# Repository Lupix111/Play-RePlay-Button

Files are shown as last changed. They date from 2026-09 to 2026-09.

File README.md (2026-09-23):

# Play/Replay







**Play/Replay** turns a Raspberry Pi Pico into a hardware-backed macro recorder for keyboard and mouse input. Press a button, do things on your PC, press it again and the exact sequence of keystrokes and mouse movement, down to the MILLISECOND, is stored on the Pico's own flash. Press the second button and it plays back on any USB host, looping forever until you stop it. No host PC or driver required.

## Why this exists

Most macro recorder tools live entirely in software on one machine: they hook the OS, store the macro in a config file, and replay it through the same OS's input APIs. That's bull-dookie (breaks across reboots, requires the software running, tied to one OS) and it can't target a *different* machine than the one you recorded on.

Play/Replay splits the job in two:

- **The Capture** happens at the OS level on a source PC because that's the only place you can reliably see input from *any* keyboard, including a laptop's built-in one, which never appears on an external USB bus.
- **Storage and playback** happen entirely on the Pico, as a real USB HID device. Once a macro is recorded the Pico can be unplugged from the source PC and plugged into any other USB host, it will type and click exactly like a human, **indistinguishable** at the protocol level from a real keyboard/mouse.

## Features

- Millisecond-accurate timing between every event (key press/release, mouse move, click, scroll)
- Two-button workflow: button 1 toggles recording, button 2 toggles looping playback (repeats forever until pressed again, even mid-sequence)
- Macros persist in flash (LittleFS) can survive power loss, no host PC needed for playback
- Works with **any** keyboard, including laptop-integrated ones (capture is OS-level, not USB-level)
- Relative mouse movement, compatible with `Mouse.h`'s HID model
- Onboard RGB LED status feedback (solid red = recording, solid green = playing, pulsing blue = idle)
- No visible window, no interruption of full-screen applications while capturing, safe to use with games
- Automatic serial reconnection: unplugging/replugging the Pico never freezes the PC-side script
- Interactive COM-port picker, or fully silent/headless operation for background use
- One Pico, one USB cable, composite USB device (Serial CDC + Keyboard + Mouse HID simultaneously)!

## Hardware requirements

- Raspberry Pi Pico (RP2040), any variant with enough flash for the macros you plan to record. Tested on a **YD-RP2040** board with onboard NeoPixel and 16MB of flash memory.
- 2 momentary push buttons, wired between a GPIO pin and GND (internal pull-ups are used, no external resistors needed)
- **Avoid GPIO26-29 for the buttons.** Those double as ADC0-3 and on several RP2040 boards are also tied to onboard analog dividers. That combination fights the internal pull-up and can read as noisy/floating instead of a clean HIGH when idle causing random "button pressed" detections. Any other GPIO (like GP14, GP15, GP22) works fine.
- If your board has an onboard NeoPixel (like the YD-RP2040's, on GPIO23) check whether the solder-bridge connecting the data line to the LED is actually closed on your revision, on some boards it isn't by default.
- A single USB cable to the source PC for recording: unplug and move to the target machine for playback

## Software requirements

- [Arduino IDE](https://www.arduino.cc/en/software) with the [arduino-pico](https://github.com/earlephilhower/arduino-pico) board package (Earle Philhower's RP2040 core), provides 'Keyboard.h', 'Mouse.h', and 'LittleFS.h'
- [Adafruit NeoPixel library](https://github.com/adafruit/Adafruit_NeoPixel) (via Library Manager), for the status LED
- Python 3.8+ on the source PC, with: pip install pynput pyserial

## Installation

1. Install the arduino-pico board package via Boards Manager in Arduino IDE, and the Adafruit NeoPixel library via Library Manager.
2. In **Tools -> Flash Size**, reserve a filesystem partition for LittleFS (**required!!!** The sketch will fail to mount storage otherwise). I'm using 15MB for the FS and 1MB for the code.
3. Open 'pico_macro_recorder.ino', adjust 'RECORD_BUTTON_PIN' / 'PLAY_BUTTON_PIN' and 'LED_PIN' to match your wiring (avoid GP26-29, see [Hardware requirements](#hardware-requirements)), and upload it to the Pico.
4. On the source PC, install the Python dependencies and run:
   
   python input_forwarder.py            # interactive port picker
   python input_forwarder.py --port COM5             # or specify directly (Windows)
   python input_forwarder.py --port /dev/ttyACM0      # or (Linux/macOS)

## Usage

1. Plug the Pico into your source PC. Make sure 'input_forwarder.py' is running (see [Running headless](#running-headless) to have it start automatically and silently).
2. Press button 1 to start recording (LED turns solid red). Do whatever you want captured.
3. Press button 1 again to stop (LED returns to the idle pulse). The macro is now saved on the Pico's flash.
4. Unplug the Pico and plug it into the target machine (or leave it on the same one).
5. Press button 2 to start looping playback (LED turns solid green), it repeats the macro continuously.
6. Press button 2 again at any point to stop it immediately (LED returns to the idle pulse).

## Running headless

Because 'input_forwarder.py' has no GUI and creates no window running it in the background never steals focus or interrupts whatever is on screen, including full-screen applications and games. To have it start automatically without any visible window:

- **Windows**: run it with 'pythonw.exe' instead of 'python.exe' (no console window at all), passing '--port COMx' explicitly (this also skips the interactive menu, which needs a console to display).
- **macOS**: use a [LaunchAgent](https://developer.apple.com/library/archive/documentation/MacOSX/Conceptual/BPSystemStartup/Chapters/CreatingLaunchdJobs.html) ('~/Library/LaunchAgents/*.plist') to start it at login.
- **Linux**: use a systemd user service, or simply 'nohup python3 input_forwarder.py --port /dev/ttyACM0 &'.

## Storage capacity

Each event is stored as a short text line (roughly 8–20 bytes depending on the event type). On a 16 MB flash Pico, that translates to **on the order of a million events**, which in practice means several hours of typical usage (mouse movement is the dominant factor since keyboards generate comparatively few events). Durations shrink significantly if you record continuous high-polling-rate mouse movement and can be extended further with delta compression if needed.

## Known limitations

- **Terms of service**: replaying recorded input in online multiplayer games very likely violates the game's ToS independent of whether it's technically detectable. Use responsibly and at your own risk, lmao.
- **Text playback is timing-based, not text-based**: this is not an autotype tool with instant text injection, it reproduces the original timing down to the last minute detail (heh) including any hesitations or corrections that were part of the original recording.
- **No absolute mouse positioning**: 'Mouse.h' only supports relative movement so playback accuracy depends on the target screen resolution/cursor state matching the recording session closely.
- **ADC-capable GPIOs (26-29) are unreliable for buttons!!!** on several RP2040 boards, see [Hardware requirements](#hardware-requirements).

## Contributing

Issues and pull requests are welcome in particular around delta/varint compression for longer recordings, dual-role USB host+device wiring for on-device (non-PC-assisted) capture and cross-platform packaging of the Python forwarder. My gf contributed to this project by making me not crashout when I foolishly soldered the record button to pin 29 and it was bugging out.

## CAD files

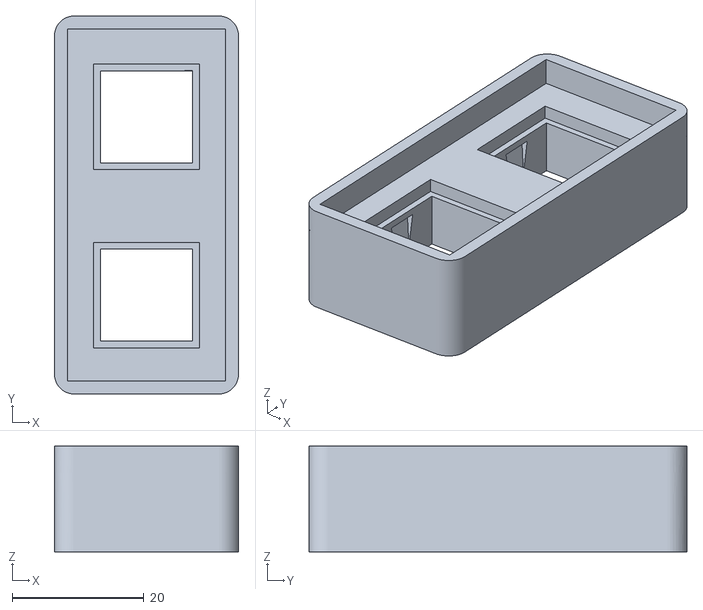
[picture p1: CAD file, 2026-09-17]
Play_Replay top.stl
27.9 x 57.3 x 16.0

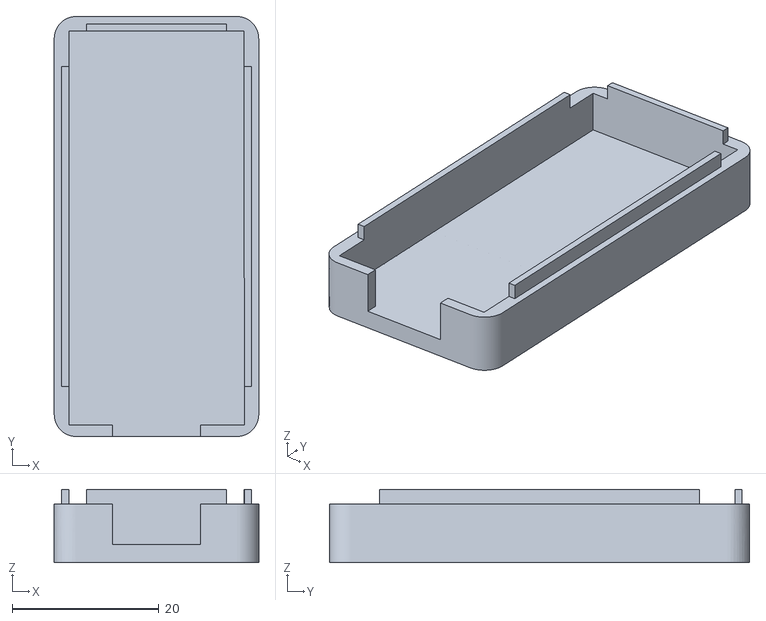
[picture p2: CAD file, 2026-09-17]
Play_Replay bottom.stl
27.9 x 57.3 x 10.0

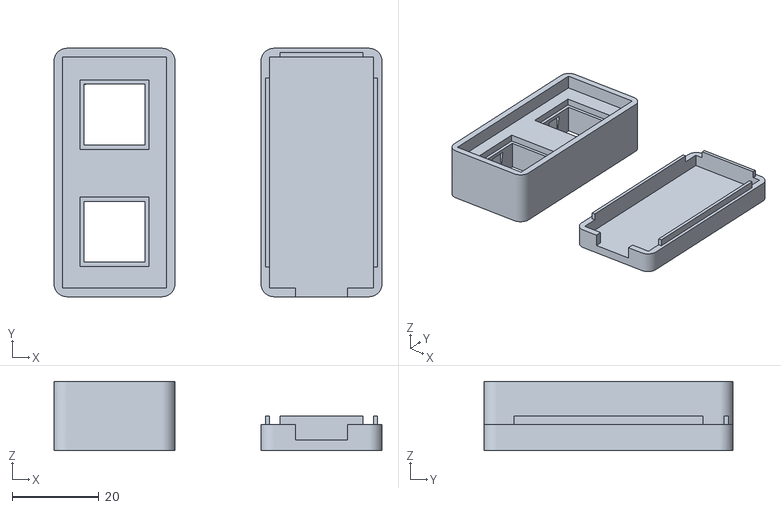
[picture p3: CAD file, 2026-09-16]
Play_Replay button v1.stl
75.6 x 57.3 x 16.0

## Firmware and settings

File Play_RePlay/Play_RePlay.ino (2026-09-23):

//Made with love by Emanuele Carlino
#include <Keyboard.h>
#include <Mouse.h>
#include <LittleFS.h>
#include <Adafruit_NeoPixel.h>
#include <math.h>

const int LED_PIN = 23;
const int LED_COUNT = 1;
Adafruit_NeoPixel pixel(LED_COUNT, LED_PIN, NEO_GRB + NEO_KHZ800);

const uint8_t IDLE_MAX_BRIGHTNESS = 255;   // 0-255, kept low so idle breathing isn't blinding
const unsigned long IDLE_PULSE_PERIOD_MS = 1000;  // full breathe in/out cycle

// ---------------- Pin configuration ----------------
const int RECORD_BUTTON_PIN = 5;   // Button 1: start/stop recording
const int PLAY_BUTTON_PIN   = 22;   // Button 2: play last recording

const unsigned long DEBOUNCE_MS = 50;
const char* MACRO_FILE_PATH = "/macro.txt";

// ---------------- State machine ----------------
enum SystemState { STATE_IDLE, STATE_RECORDING, STATE_PLAYING };
SystemState currentState = STATE_IDLE;

File macroFile;

// ---------------- Debounced button helper ----------------
struct DebouncedButton {
  int pin;
  int lastReading;
  int stableState;
  unsigned long lastChangeTime;
};

DebouncedButton recordButton = { RECORD_BUTTON_PIN, HIGH, HIGH, 0 };
DebouncedButton playButton   = { PLAY_BUTTON_PIN,   HIGH, HIGH, 0 };

// Returns true exactly once, on the transition from released to pressed
// (buttons are wired active-LOW using the internal pull-up).
bool buttonPressedEdge(DebouncedButton &btn) {
  int reading = digitalRead(btn.pin);
  if (reading != btn.lastReading) {
    btn.lastChangeTime = millis();
  }
  bool edge = false;
  if ((millis() - btn.lastChangeTime) > DEBOUNCE_MS) {
    if (reading != btn.stableState) {
      btn.stableState = reading;
      if (btn.stableState == LOW) {
        edge = true;  // just pressed
      }
    }
  }
  btn.lastReading = reading;
  return edge;
}

// ---------------- Setup ----------------
void setup() {
  pinMode(RECORD_BUTTON_PIN, INPUT_PULLUP);
  pinMode(PLAY_BUTTON_PIN, INPUT_PULLUP);

  Serial.begin(115200);

  Serial.println("[boot] Serial up");

  Keyboard.begin();
  Serial.println("[boot] Keyboard.begin() done");
  Mouse.begin();
  Serial.println("[boot] Mouse.begin() done");

  pixel.begin();
  Serial.println("[boot] pixel.begin() done");
  pixel.show();  // off until the first loop() iteration sets the idle pulse
  Serial.println("[boot] pixel.show() done");

  Serial.println("[boot] mounting LittleFS...");
  if (!LittleFS.begin()) {
    // First boot / corrupted filesystem: format once and retry.
    Serial.println("[boot] mount failed, formatting (can take a while on large flash)...");
    LittleFS.format();
    Serial.println("[boot] format complete, remounting...");
    LittleFS.begin();
  }
  Serial.println("[boot] setup() complete, entering loop()");
}

// ---------------- LED feedback ----------------
void setSolidColor(uint8_t r, uint8_t g, uint8_t b) {
  pixel.setPixelColor(0, pixel.Color(r, g, b));
  pixel.show();
}

// Non-blocking breathing blue pulse, driven entirely off millis() so it
// never interferes with button polling or the recording/playback timing
void updateIdlePulse() {
  float phase = (millis() % IDLE_PULSE_PERIOD_MS) / (float)IDLE_PULSE_PERIOD_MS;
  float wave = (sin(phase * 2.0 * PI) + 1.0) / 2.0;  // 0.0 .. 1.0
  uint8_t brightness = (uint8_t)(wave * IDLE_MAX_BRIGHTNESS);
  pixel.setPixelColor(0, pixel.Color(0, 0, brightness));
  pixel.show();
}


void startRecording() {
  if (LittleFS.exists(MACRO_FILE_PATH)) {
    LittleFS.remove(MACRO_FILE_PATH);
  }
  macroFile = LittleFS.open(MACRO_FILE_PATH, "w");
  currentState = STATE_RECORDING;
  setSolidColor(255, 0, 0);  // solid red while recording
  Serial.println("REC:1");
}

void stopRecording() {
  if (macroFile) {
    macroFile.close();
  }
  currentState = STATE_IDLE;
  Serial.println("REC:0");
}

void handleRecordButton() {
  if (!buttonPressedEdge(recordButton)) return;

  if (currentState == STATE_IDLE) {
    startRecording();
  } else if (currentState == STATE_RECORDING) {
    stopRecording();
  }
  // Ignored if currently playing.
}

// Reads whatever is available on Serial and appends complete lines
// to the macro file while a recording is in progress
void captureSerialToFile() {
  static String lineBuffer;
  while (Serial.available() > 0) {
    char c = (char)Serial.read();
    if (c == '\n') {
      lineBuffer.trim();
      if (lineBuffer.length() > 0 && macroFile) {
        macroFile.println(lineBuffer);
      }
      lineBuffer = "";
    } else if (c != '\r') {
      lineBuffer += c;
    }
  }
}

// ---------------- Playback ----------------
uint8_t hexPairToByte(const String &hex) {
  auto hexDigit = [](char c) -> uint8_t {
    if (c >= '0' && c <= '9') return c - '0';
    if (c >= 'a' && c <= 'f') return c - 'a' + 10;
    if (c >= 'A' && c <= 'F') return c - 'A' + 10;
    return 0;
  };
  if (hex.length() < 2) return 0;
  return (hexDigit(hex[0]) << 4) | hexDigit(hex[1]);
}

// Splits a comma-separated line into at most maxFields tokens.
int splitCSV(const String &line, String fields[], int maxFields) {
  int count = 0;
  int start = 0;
  while (count < maxFields) {
    int idx = line.indexOf(',', start);
    if (idx == -1) {
      fields[count++] = line.substring(start);
      break;
    }
    fields[count++] = line.substring(start, idx);
    start = idx + 1;
  }
  return count;
}

void playbackEvent(const String &line) {
  String fields[5];
  int n = splitCSV(line, fields, 5);
  if (n < 2) return;

  if (fields[0] == "K") {
    // K,<1|0>,<hex_keycode>,<delta_ms>
    if (n < 4) return;
    bool pressed = (fields[1] == "1");
    uint8_t code = hexPairToByte(fields[2]);
    unsigned long deltaMs = fields[3].toInt();

    delay(deltaMs);
    if (pressed) {
      Keyboard.press((char)code);
    } else {
      Keyboard.release((char)code);
    }

  } else if (fields[0] == "M") {
    if (fields[1] == "MOVE" && n >= 5) {
      // M,MOVE,<dx>,<dy>,<delta_ms>  (relative movement)
      int dx = fields[2].toInt();
      int dy = fields[3].toInt();
      unsigned long deltaMs = fields[4].toInt();

      delay(deltaMs);
      Mouse.move(dx, dy, 0);

    } else if (fields[1] == "CLICK" && n >= 4) {
      // M,CLICK,<left|right|middle>,<1|0>,<delta_ms>
      String buttonName = fields[2];
      bool pressed = (fields[3] == "1");
      unsigned long deltaMs = (n >= 5) ? fields[4].toInt() : 0;

      uint8_t mouseButton = MOUSE_LEFT;
      if (buttonName == "right") mouseButton = MOUSE_RIGHT;
      else if (buttonName == "middle") mouseButton = MOUSE_MIDDLE;

      delay(deltaMs);
      if (pressed) {
        Mouse.press(mouseButton);
      } else {
        Mouse.release(mouseButton);
      }

    } else if (fields[1] == "SCROLL" && n >= 4) {
      // M,SCROLL,<dy>,<delta_ms>
      int dy = fields[2].toInt();
      unsigned long deltaMs = fields[3].toInt();

      delay(deltaMs);
      Mouse.move(0, 0, dy);
    }
  }
}

void playRecordingOnce(bool &stopRequested) {
  File f = LittleFS.open(MACRO_FILE_PATH, "r");
  setSolidColor(0,255,0);
  if (!f) {
    stopRequested = true;  // nothing to play; behave as if stop was requested
    return;
  }

  while (f.available()) {
    String line = f.readStringUntil('\n');
    line.trim();
    if (line.length() > 0) {
      playbackEvent(line);
    }

    // Checked after EVERY event, not just after a full pass, so pressing
    // the play button stops playback immediately instead of waiting for
    // the whole (possibly looping) sequence to finish.
    if (buttonPressedEdge(playButton)) {
      stopRequested = true;
      break;
    }
  }

  f.close();
}

void stopPlayback() {
  // Release everything, in case playback was interrupted mid-press
  // (avoids "stuck" keys or held mouse buttons)
  Keyboard.releaseAll();
  Mouse.release(MOUSE_LEFT);
  Mouse.release(MOUSE_RIGHT);
  Mouse.release(MOUSE_MIDDLE);
  currentState = STATE_IDLE;
  updateIdlePulse();
}

void handlePlayButton() {
  // Only ever called from loop() while currentState == STATE_IDLE.
  if (!buttonPressedEdge(playButton)) return;
  currentState = STATE_PLAYING;
  setSolidColor(0, 255, 0);  // solid blue while playing
}

// ---------------- Main loop ----------------
void loop() {
  handleRecordButton();

  if (currentState == STATE_RECORDING) {
    captureSerialToFile();

  } else if (currentState == STATE_PLAYING) {
    bool stopRequested = false;
    playRecordingOnce(stopRequested);

    if (stopRequested) {
      stopPlayback();
    }

  } else {
    handlePlayButton();
    updateIdlePulse();
  }
}

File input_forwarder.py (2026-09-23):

"""
Script made by Emanuele Carlino, gimme a dolla if you like this!
dependencies:
    pip install pynput pyserial
usage:
    python input_forwarder.py --port COM5        (Windows)
    python input_forwarder.py --port /dev/ttyACM0 (Linux/macOS)
permissions note:
    - macOS: Settings -> Privacy & Security -> Accessibility / Input
      Monitoring must include the terminal/IDE this script runs from.
      (I have yet to test this on MacOS since I don't own a Mac)
    - Linux: on Wayland, global keyboard capture is prolly restricted by
      the compositor, on X11 it SHOULD work normally.
    - Windows: no special permission needed but antivirus software
      may flag the script for the global-hook pattern (a common false
      positive for any tool like this)
"""
import argparse
import sys
import threading
import time

try:
    import serial
except ImportError:
    sys.exit("Missing pyserial, install with: pip install pyserial")

from serial.tools import list_ports

try:
    from pynput import keyboard, mouse
except ImportError:
    sys.exit("Missing pynpum, install with: pip install pynput")

'''
Keyboard.h constants (Arduino-Pico core / Arduino Leonardo family).
Printable keys (letters, digits, symbols) use their own ASCII byte
and don't appear here; this table only covers the "special" keys
that have a dedicated non-ASCII code in Keyboard.h
'''
SPECIAL_KEY_TO_HID = {
    "shift": 0x81, "shift_r": 0x85,
    "ctrl": 0x80, "ctrl_l": 0x80, "ctrl_r": 0x84,
    "alt": 0x82, "alt_l": 0x82, "alt_r": 0x86,
    "cmd": 0x83, "cmd_l": 0x83, "cmd_r": 0x87,  #Windows/Command key
    "caps_lock": 0xC1,
    "tab": 0xB3,
    "enter": 0xB0,
    "backspace": 0xB2,
    "esc": 0xB1,
    "space": 0x20,  #space is ASCII, but pynput names it "space"
    "up": 0xDA, "down": 0xD9, "left": 0xD8, "right": 0xD7,
    "delete": 0xD4,
    "insert": 0xD1,
    "home": 0xD2,
    "end": 0xD5,
    "page_up": 0xD3,
    "page_down": 0xD6,
    "f1": 0xC2, "f2": 0xC3, "f3": 0xC4, "f4": 0xC5,
    "f5": 0xC6, "f6": 0xC7, "f7": 0xC8, "f8": 0xC9,
    "f9": 0xCA, "f10": 0xCB, "f11": 0xCC, "f12": 0xCD,
}


def key_to_hid_code(name: str) -> str:
    """
    Converts a key name (as returned by pynput) into the code that
    Keyboard.h expects as a 2-digit hex string (e.g. 'a' -> '61',
    F1 -> 'c2'), unmapped keys fall back to '00_' + the original name
    so nothing is silently lost even if a table entry is missing.
    """
    key = name.lower()
    if key in SPECIAL_KEY_TO_HID:
        return f"{SPECIAL_KEY_TO_HID[key]:02x}"
    if len(key) == 1:
        return f"{ord(key):02x}"
    # Unrecognized key (special layouts, media keys): forward the
    # raw name as a fallback, handle it on the Pico side if needed.
    return "00_" + name


class InputForwarder:
    def __init__(self, port: str, baud: int = 115200):
        self.port_name = port
        self.baud = baud
        self.ser = None            #none whenever the Pico is unplugged/unreachable
        self.recording = False
        self.last_ts = None        #perf_counter timestamp of the last forwarded event
        self.last_x = None
        self.last_y = None
        self.lock = threading.Lock()
        self.stop_event = threading.Event()
        self._open_serial()        # first connection attempt; reconnect_loop retries afterwards


                                             #connection management 
    def _open_serial(self):
        """tries to (re)open the serial port, never raises: leaves self.ser as None on failure"""
        try:
            ''' 
            write_timeout is the important part here: without it, write() can
            block FOREVER if the device is physically unplugged, which is
            exactly what made the script originally freeze and require Task Manager
            to kill it. With a timeout, a dead write turns into a normal
            catchable SerialTimeoutException instead of a permanent hang
            '''
            self.ser = serial.Serial(self.port_name, self.baud, timeout=0.05, write_timeout=0.5)
            print(f"[forwarder] Connected to {self.port_name}")
        except (serial.SerialException, OSError):
            self.ser = None

    def _drop_connection(self):
        """closes and forgets the current connection so the reconnect loop can retry."""
        with self.lock:
            if self.ser is not None:
                try:
                    self.ser.close()
                except (serial.SerialException, OSError):
                    pass
                self.ser = None
                self.recording = False
        print("[forwarder] Pico disconnected, will keep retrying in the background...")

    def reconnect_loop(self):
        """Runs for the whole lifetime of the script; reopens the port whenever it's missing."""
        while not self.stop_event.is_set():
            with self.lock:
                needs_reconnect = self.ser is None
            if needs_reconnect:
                self._open_serial()
            self.stop_event.wait(1.0)

                            #handling incoming commands from the Pico 
    def serial_listener(self):
        """reads lines from the Pico ('REC:1', 'REC:0') and updates state"""
        buf = b""
        while not self.stop_event.is_set():
            with self.lock:
                ser = self.ser
            if ser is None:
                time.sleep(0.2)
                continue
            try:
                chunk = ser.read(64)
            except (serial.SerialException, OSError):
                self._drop_connection()
                buf = b""
                continue
            if not chunk:
                continue
            buf += chunk
            while b"\n" in buf:
                line, buf = buf.split(b"\n", 1)
                line = line.strip()
                if line == b"REC:1":
                    with self.lock:
                        self.recording = True
                        self.last_ts = time.perf_counter()
                    print("[forwarder] Recording STARTED by the Pico: YOU ARE LIVE!")
                elif line == b"REC:0":
                    with self.lock:
                        self.recording = False
                    print("[forwarder] Recording STOPPED by the Pico: Recording Done")
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

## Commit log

2026-09-16 Add files via upload
    first version of the body
    [Play_Replay button v1.stl]
2026-09-23 Update Play_RePlay.ino and new functionality with LED
    fixed major issues and implemented Neopixel LED
    [Play_RePlay.ino]

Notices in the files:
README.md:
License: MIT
